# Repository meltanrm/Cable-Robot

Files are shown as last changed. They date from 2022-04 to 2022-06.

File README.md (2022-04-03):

# Cable-Robot

In this repo, you will find:
- Stl files of 3D printed parts that will enable you to make your cable robot (under Stl_files: Camera_mount, Prototype and Final_frame designs).
- Code to test the electronic setup for your cable robot (in the Electronics_testing_code folder), which you are recommended to go through in the following order:
  1. Test_motors
  2. Test_encoder
  3. Test_encoder_tracking_motor
  4. Joystick_graphs
  5. Test_joystick
- Code to run your cable robot, moving it to desired positions (Prototype_cable_robot_code).

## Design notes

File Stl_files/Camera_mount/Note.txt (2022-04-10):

All camera mount stl files, except "Raspi Backboard attached to rail slider Final v1.stl", were designed by fl0r1s. They were uploaded on Thingiverse on 21st January 2021 at this link: https://www.thingiverse.com/thing:4731754 (Accessed 2nd April 2022)

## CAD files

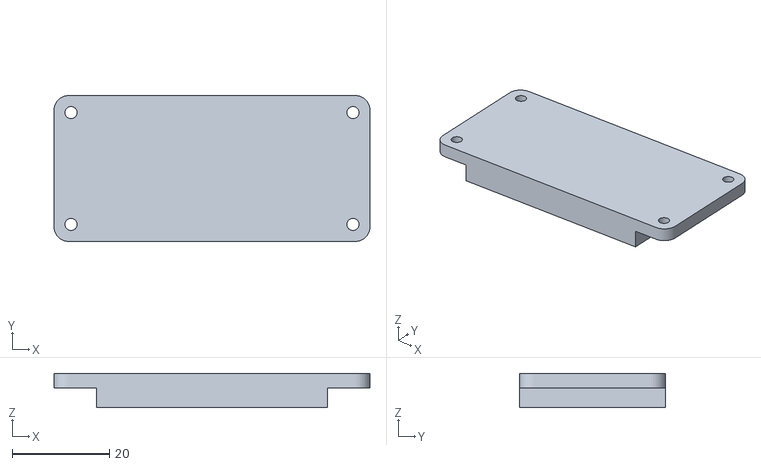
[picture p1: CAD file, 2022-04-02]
Stl_files/Camera_mount/interface.stl
65.0 x 30.0 x 7.00

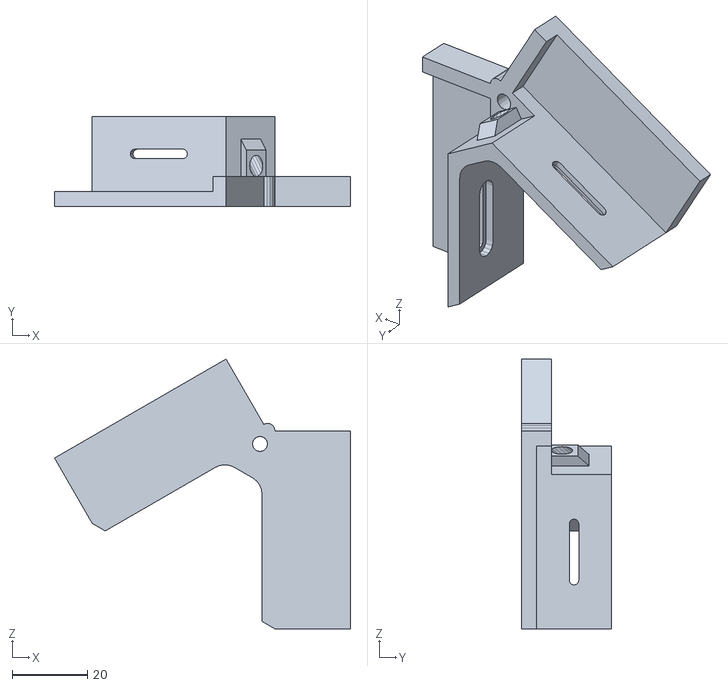
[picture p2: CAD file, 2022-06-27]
Stl_files/Final_frame/PlatformCorner.stl
78.5 x 24.0 x 71.6

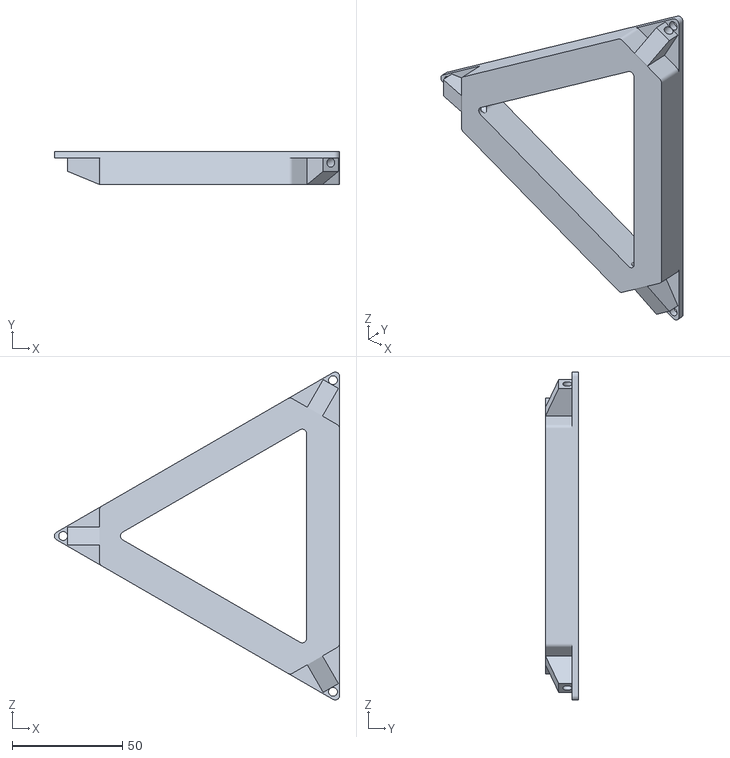
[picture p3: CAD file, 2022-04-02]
Stl_files/Prototype/Platform.stl
129.6 x 15.0 x 149.0

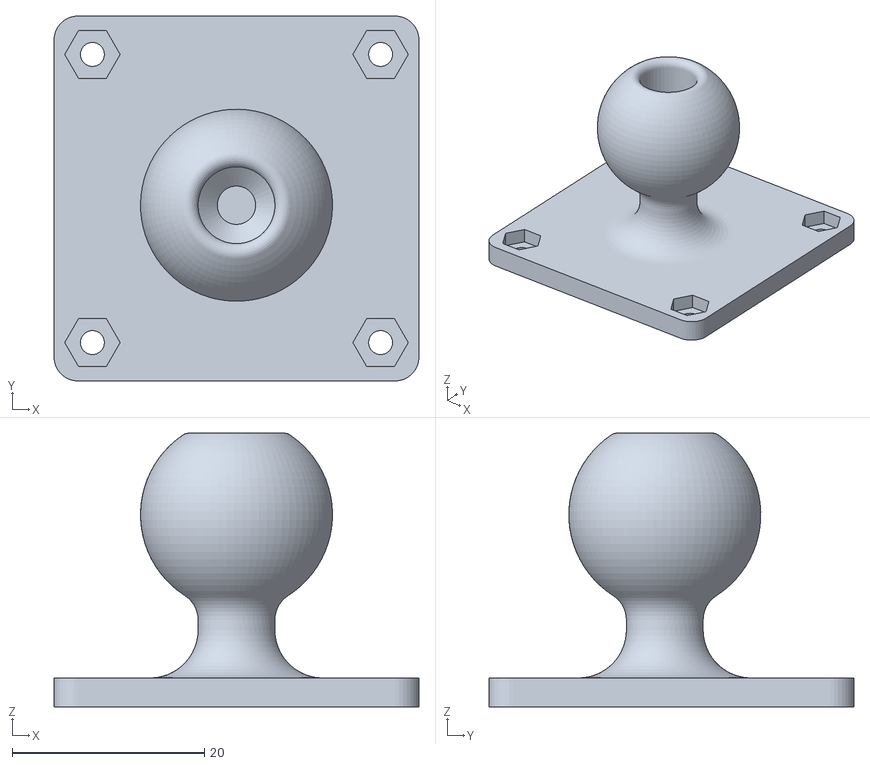
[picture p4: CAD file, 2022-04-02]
Stl_files/Camera_mount/ball.stl
38.0 x 38.0 x 28.5

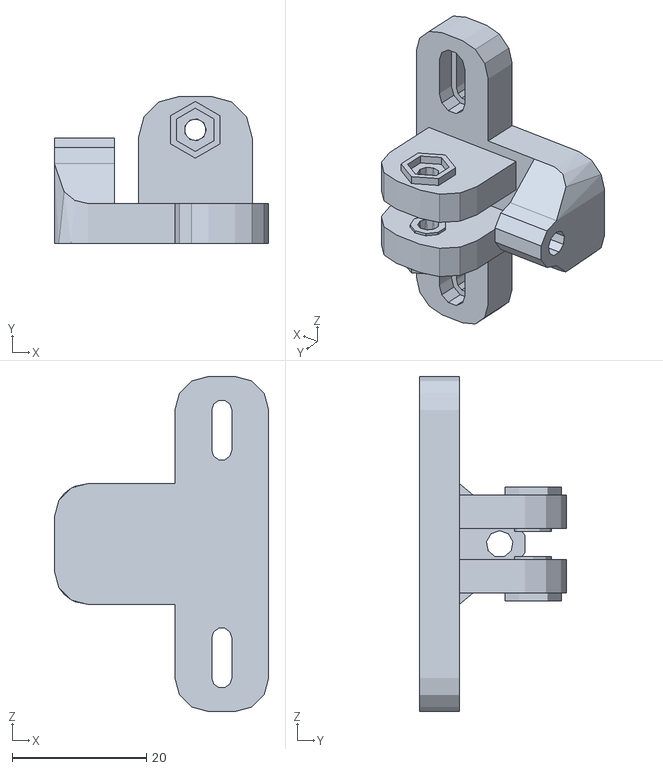
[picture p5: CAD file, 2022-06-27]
Stl_files/Final_frame/LineAnchors.stl
32.0 x 22.0 x 50.0

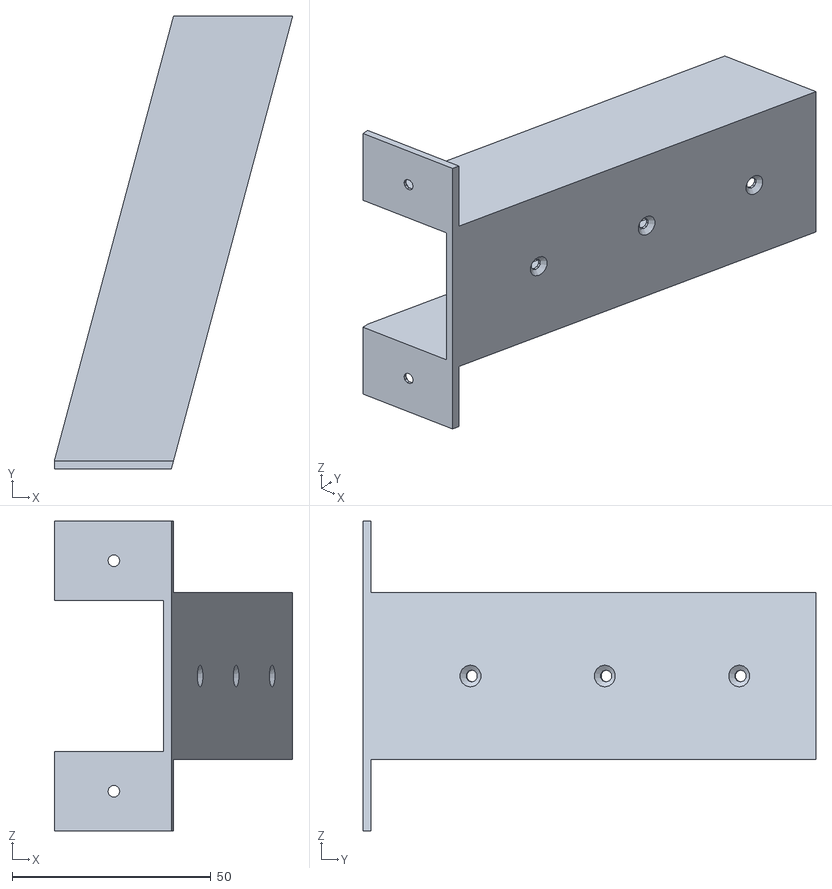
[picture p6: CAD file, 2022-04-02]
Stl_files/Prototype/OuterLeaningCase.stl
60.0 x 114.0 x 78.0

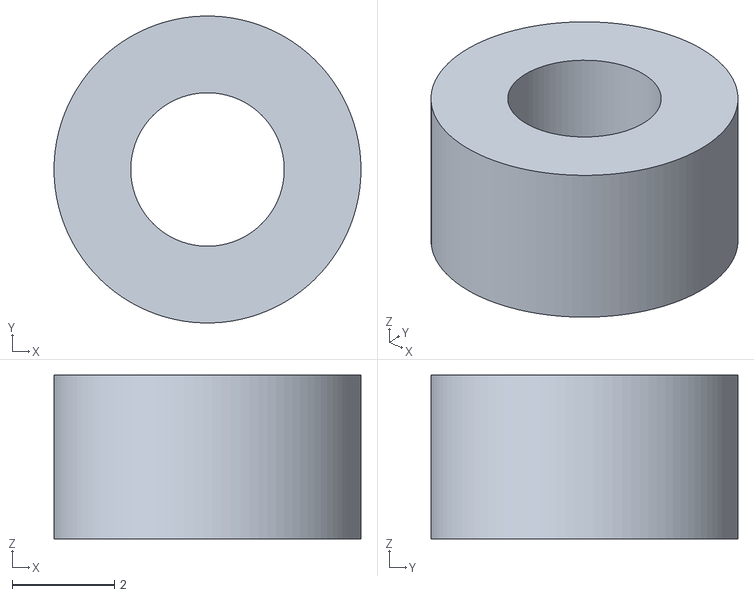
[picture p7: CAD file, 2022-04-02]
Stl_files/Camera_mount/spacer.stl
6.00 x 6.00 x 3.20

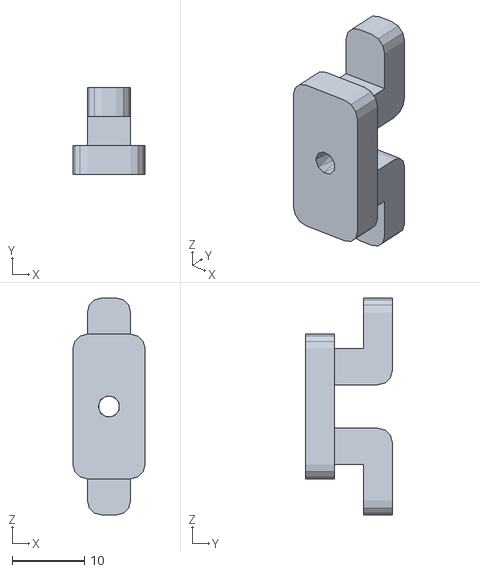
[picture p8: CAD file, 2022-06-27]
Stl_files/Final_frame/PlatformSlider.stl
10.0 x 12.0 x 30.0

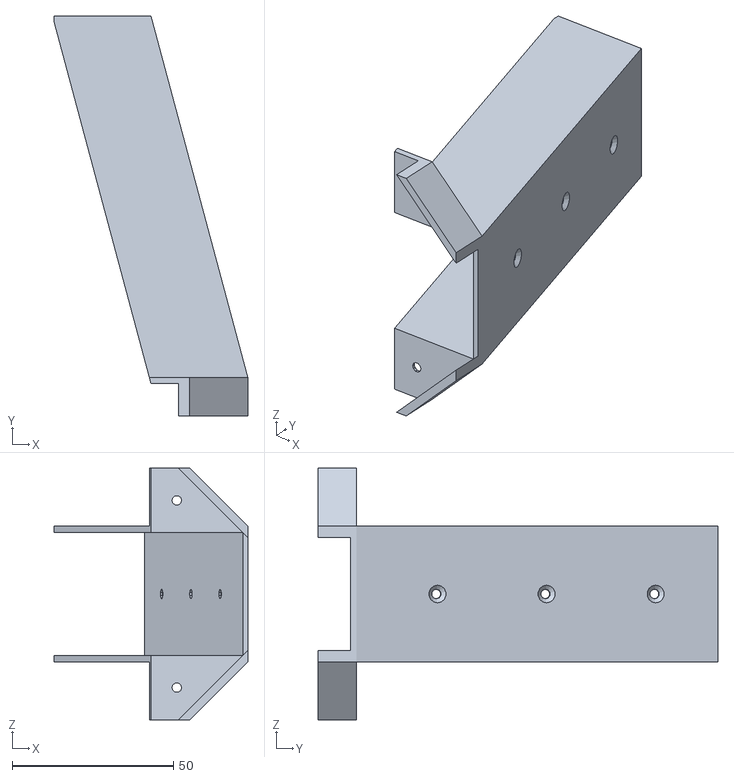
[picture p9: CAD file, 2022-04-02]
Stl_files/Prototype/Leaning beam case v2.stl
60.0 x 124.0 x 78.0

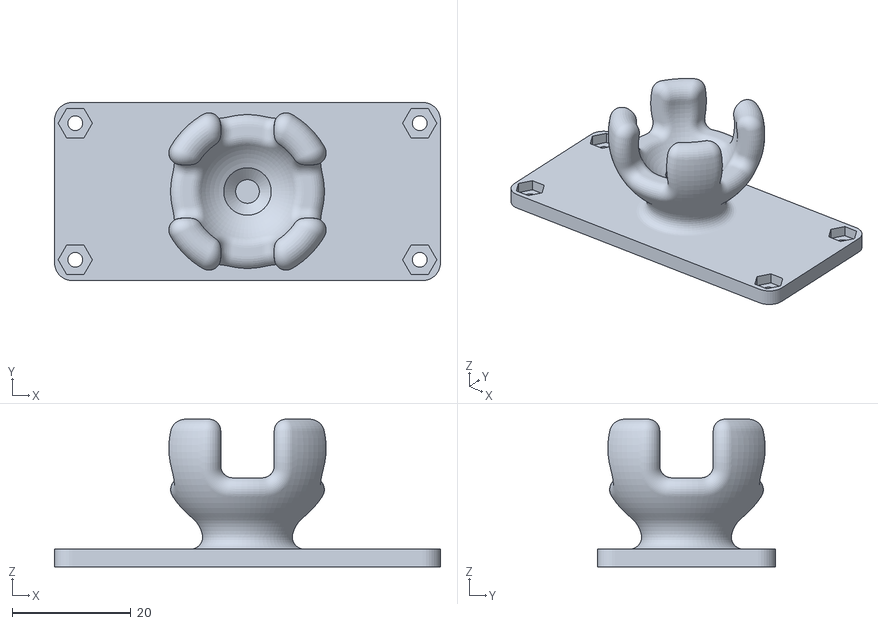
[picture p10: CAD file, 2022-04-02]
Stl_files/Camera_mount/socket.stl
65.0 x 30.0 x 24.9

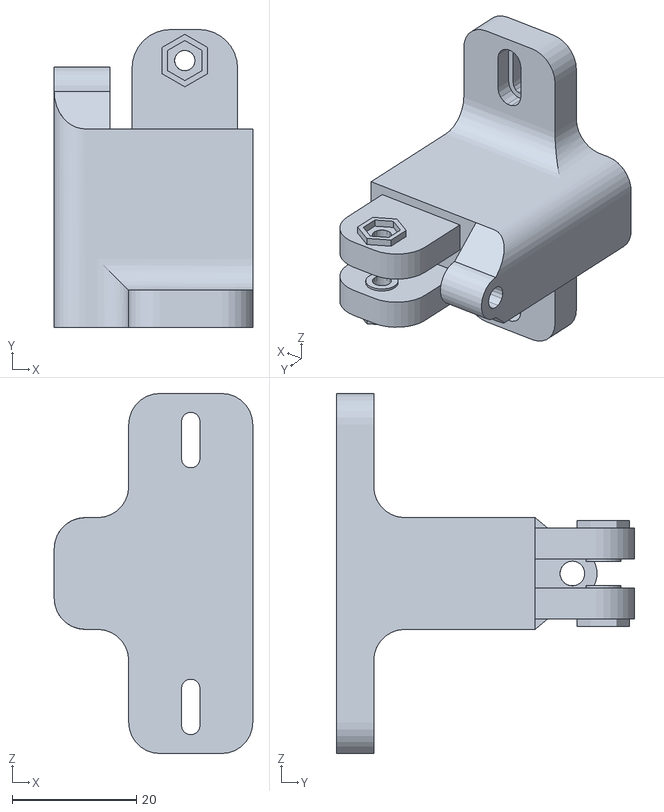
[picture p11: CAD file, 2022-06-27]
Stl_files/Final_frame/LineAnchors_C.stl
32.0 x 48.0 x 58.0

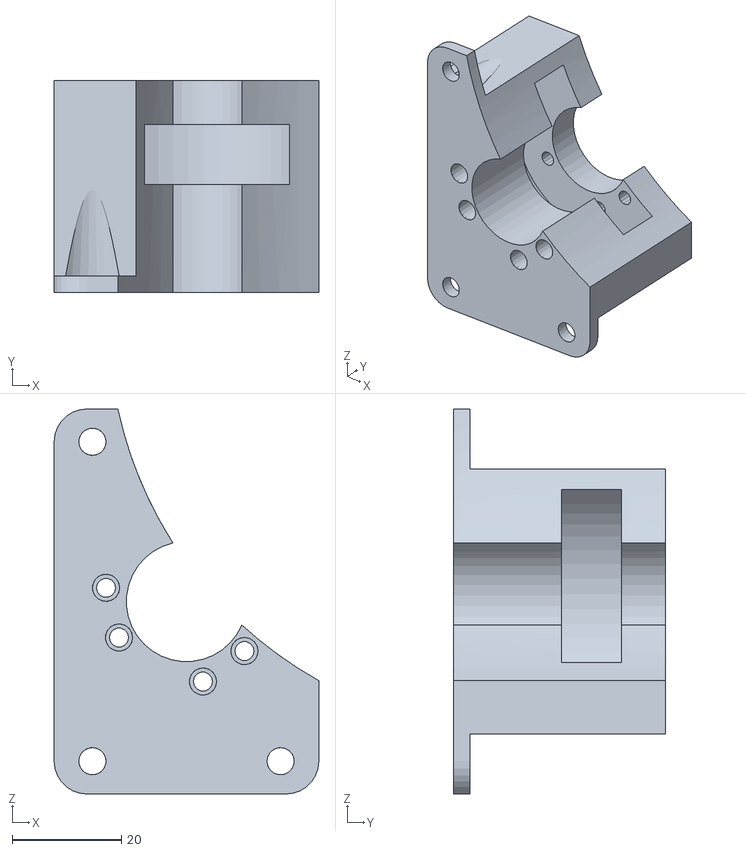
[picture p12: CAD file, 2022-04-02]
Stl_files/Prototype/Encoder_bracket.stl
48.4 x 38.7 x 70.4

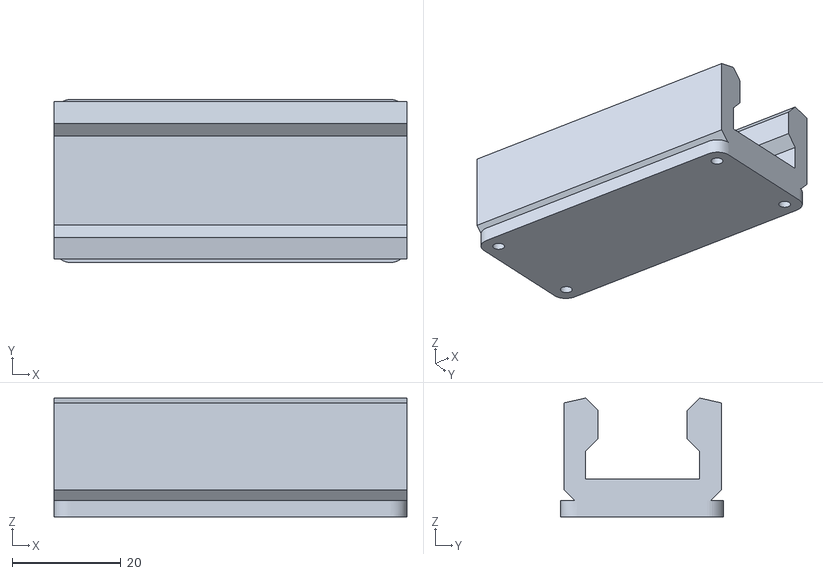
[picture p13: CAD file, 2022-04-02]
Stl_files/Camera_mount/Raspi Backboard attached to rail slider Final v1.stl
65.0 x 30.0 x 21.9

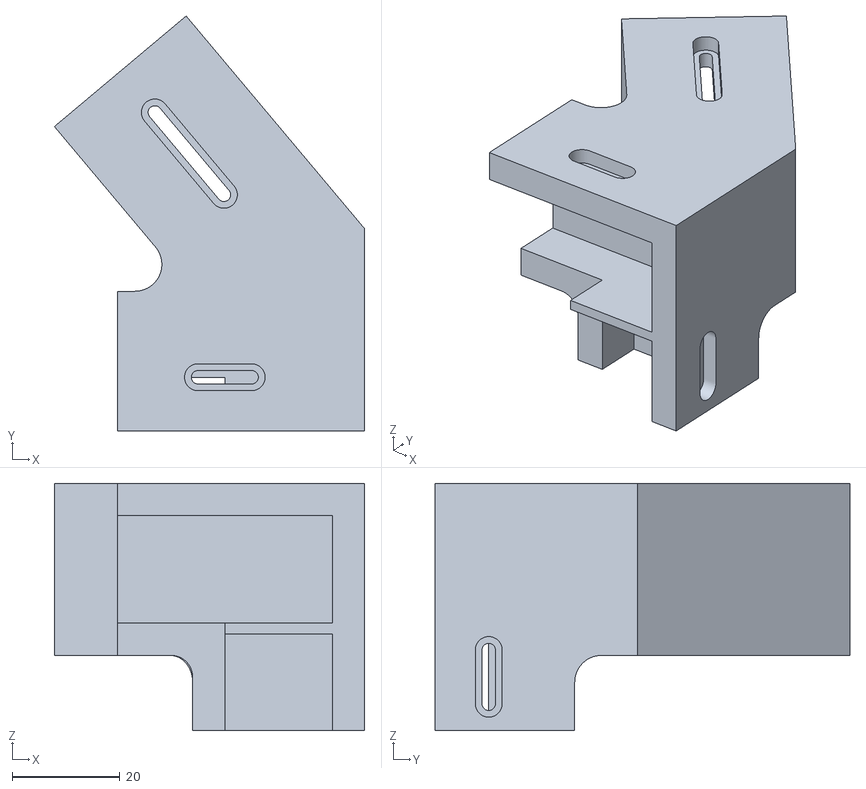
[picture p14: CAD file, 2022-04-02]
Stl_files/Final_frame/LowerConnect_finalShortBeam.stl
57.7 x 77.2 x 46.0

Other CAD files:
Stl_files/Final_frame/LowerConnect_finalMirror.stl
Stl_files/Final_frame/UpperConnect_finalShortBeam.stl
Stl_files/Final_frame/DiagonalBeamBracket_2.stl
Stl_files/Final_frame/DiagonalBeamBracket_2_Mirror.stl
Inventor_Files/CalibrationRig_ver2.ipt
Inventor_Files/PlatformSlider.ipt
Stl_files/Final_frame/DiagonalBeamBracket.stl
Stl_files/Final_frame/DiagonalBeamBracket_Mirror.stl
Stl_files/Final_frame/LowerConnect_final.stl
Stl_files/Final_frame/UpperConnect_final.stl

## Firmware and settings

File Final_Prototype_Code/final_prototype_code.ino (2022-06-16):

// Code to move final design of cable robot - 16 June 2022

// NOTES:
// Set the serial monitor from newline --> no line ending
// All input coordinates are in cm
// All coordinates, cable lengths and spool dimensions are in cm

// Pins and motors set-up: direction and steps
  const int dirPinA = 10; // motor A
  const int stepPinA = 11;
  const int dirPinB = 6; // motor B
  const int stepPinB = 7;
  const int dirPinC = 12; // motor C
  const int stepPinC = 13;
  const int dirPinD = 8; // motor D spool
  const int stepPinD = 9;

// Initialising coordinates of platform
float P[3] = {0, 0, 0};

void setup() {
  Serial.begin(9600);

  // Declaring pins as outputs
    pinMode(stepPinA, OUTPUT);
    pinMode(dirPinA, OUTPUT);
    pinMode(stepPinB, OUTPUT);
    pinMode(dirPinB, OUTPUT);
    pinMode(stepPinC, OUTPUT);
    pinMode(dirPinC, OUTPUT);
    pinMode(stepPinD, OUTPUT);
    pinMode(dirPinD, OUTPUT);
}

// Function to receive input coordinates:

void recvInputCoord() {

  float bounds_x[] = {-33.5,28.0};
  float bounds_y[] = {-50.5,50.5};
  float bounds_z[] = {0,30};
  
  bool dum = true;

  while(dum){
    int counter = 0;
    Serial.println("Please input X coordinate: "); //Prompt User for Input
    while (Serial.available() == 0) {
    }
    P[0] = Serial.parseInt();
  
    Serial.println("Please input Y coordinate: "); //Prompt User for Input
    while (Serial.available() == 0) {
    }
    P[1] = Serial.parseInt();
  
    Serial.println("Please input Z coordinate: "); //Prompt User for Input
    while (Serial.available() == 0) {
    }
    P[2] = Serial.parseInt();

    if ((P[0] < bounds_x[0]) || (P[0] > bounds_x[1])) {
      counter++;
    }
    if ((P[1] < bounds_y[0]) || (P[1] > bounds_y[1])) {
      counter++;
    }
    if ((P[2] < bounds_z[0]) || (P[2] > bounds_z[1])) {
      counter++;
    }
    if (counter == 0) {
      dum = false;
      break;
    }

    Serial.println("Sorry, you input was out of bounds.");
    Serial.println("Please input coordinates within the boundaries.");
    Serial.println("X bounds: -33.5 to 28.0 cm");
    Serial.println("Y bounds: -50.5 to 50.5 cm");
    Serial.println("Z bounds: 0 to 30 cm"); 
  }
  
  Serial.println("Your input coordinates are: ");
  Serial.println(P[0]);
  Serial.println(P[1]);
  Serial.println(P[2]);
}

// Function to calculate cable lengths:

float cableLength(float coord1[3], float coord2[3]) {
     float diff[3];
     float modResult;
     for (int i = 0; i < 3; i++) {
        diff[i] = (coord2[i] - coord1[i]); 
     }
     modResult = (sqrt(sq(diff[0]) + sq(diff[1]) + sq(diff[2])));  
     
     return modResult;
}

void loop() {

  // Initialise cableLength function
     float cableLength(float coord1[], float coord2[]);

  // Height of prototype
    float height_upper = 56.4196 - 26.6; // relative to height of line anchors
    float height_lower = 0; // height of line anchors set as zero

  // Coordinates of line rollers for D spool (used below)
    float D1[] = {4.8948, 0, height_upper};
    float D2[] = {-12.5185, -10.0536, height_upper};
    float D3[] = {-12.5185, 10.0536, height_upper};

  // Coordinates of platform vertices at starting position
    float P1_0[]= {D1[0], D1[1], height_lower};
    float P2_0[]= {D2[0], D2[1], height_lower};
    float P3_0[]= {D3[0], D3[1], height_lower};

  // Coordinates of line anchors
    float a1[] = {28.6891, -41.2129, height_lower};
    float a2[] = {11.2757, -51.2665, height_lower};
    float b1[] = {28.6891, 41.2129, height_lower};
    float b2[] = {11.2757, 51.2665, height_lower};
    float c1[] = {-34.0, -10.0536, height_lower};
    float c2[] = {-34.0, 10.0536, height_lower};

  // Cable lengths at starting point
    // Two cables (1 and 2) come from each of the spools (A to C)
    // Three cables come from spool D
    // Distance calculated: line anchors to platform vertices
      float l_a1_0 = 47.5885;
      float l_a2_0 = 47.5885;
      float l_b1_0 = 47.5885;
      float l_b2_0 = 47.5885;
      float l_c1_0 = 21.4815;
      float l_c2_0 = 21.4815;
      float l_d1_0 = height_upper; // Applies only at start when cables are vertical
      float l_d2_0 = height_upper; 
      float l_d3_0 = height_upper;
  
  // Receives input coordinates
    recvInputCoord();

  // Coordinates of 3 platform vertices at new position
    float v1[] = {D1[0] + P[0], D1[1] + P[1], D1[2] + P[2]};
    float v2[] = {D2[0] + P[0], D2[1] + P[1], D2[2] + P[2]}; 
    float v3[] = {D3[0] + P[0], D3[1] + P[1], D3[2] + P[2]};

 // Cable lengths at new position
    // Distance calculated: line anchors to platform vertices
    float l_a1 = cableLength(a1, v1);
    float l_a2 = cableLength(a2, v2);
    float l_b1 = cableLength(b1, v1);
    float l_b2 = cableLength(b2, v3);
    float l_c1 = cableLength(c1, v2);
    float l_c2 = cableLength(c2, v3);
    float l_d1 = cableLength(v1, D1);
    float l_d2 = cableLength(v2, D2);
    float l_d3 = cableLength(v3, D3);
      

 // Calculate cable length difference: desired length - current length
    // Only required to be calculated for one cable per spool - works geometrically 
    float lineDiffa1 = l_a1 - l_a1_0; 
    float lineDiffb1 = l_b1 - l_b1_0;
    float lineDiffc1 = l_c1 - l_c1_0;
    float lineDiffd1 = l_d1 - l_d1_0; 

 // Moving the motors by desired amount
    // Finding the corresponding rotations required
    float spoolDiameter = 11;
    float spoolCirc = PI * spoolDiameter;
    
    // 200 motor steps per motor turn --> 10 motor turns = 1 spool turn
    int motorSteps_a1 = ((lineDiffa1) / (spoolCirc)) * 10 * 200; 
    int motorSteps_b1 = ((lineDiffb1) / (spoolCirc)) * 10 * 200;
    int motorSteps_c1 = ((lineDiffc1) / (spoolCirc)) * 10 * 200;
    int motorSteps_d1 = ((lineDiffd1) / (spoolCirc)) * 10 * 200;

    // Absolute values of motor steps
    int abs_a = abs(motorSteps_a1);
    int abs_b = abs(motorSteps_b1);
    int abs_c = abs(motorSteps_c1);
    int abs_d = abs(motorSteps_d1);
  
    int stepsArray[] = {abs_a,abs_b,abs_c,abs_d};
    
        // for checking the number of motor steps per spool:
         /* Serial.println("These are the motor steps:");
            Serial.println(abs_a);
            Serial.println(abs_b);
            Serial.println(abs_c);
            Serial.println(abs_d); */

    // Large 'for' loop to set motors to move at the same time
      // Loop continues until value of counter reaches value of motor steps
      // For all 4 spools: set direction of turns, comparison of counter vs. motorsteps, 
      // set pin HIGH, delay, set pin LOW.
    
      // Compare all 4 values to find highest
      int highVal = stepsArray[0];
      for (int n = 1; n < 4; n++) {
         if (stepsArray[n] > highVal) {
              highVal = stepsArray[n];
         }
      }
  
      // Counters
      int count_a = 0;
      int count_b = 0;
      int count_c = 0;
      int count_d = 0;

      for(int x = 0; x < highVal; x++){
        // Set direction of pins
          if (lineDiffa1 > 0){
            digitalWrite(dirPinA, LOW);
          }
          else {
            digitalWrite(dirPinA, HIGH);
          }
          
          if (lineDiffb1 > 0){
            digitalWrite(dirPinB, HIGH);
          }
          else {
            digitalWrite(dirPinB, LOW);
          }
          
          if (lineDiffc1 > 0){
            digitalWrite(dirPinC, LOW);
          }
          else {
            digitalWrite(dirPinC, HIGH);
          }
          
          if (lineDiffd1 > 0){
            digitalWrite(dirPinD, HIGH);
          }
          else {
            digitalWrite(dirPinD, LOW);
          }

        // Set pins HIGH
          if (count_a < abs_a) {
            digitalWrite(stepPinA, HIGH);
          }
          if (count_b < abs_b) {
            digitalWrite(stepPinB, HIGH);
          }
          if (count_c < abs_c) {
            digitalWrite(stepPinC, HIGH);
          }
          if (count_d < abs_d) {
            digitalWrite(stepPinD, HIGH);
          }


        // Delay 
          if (count_a < abs_a||count_b < abs_b||count_c < abs_c||count_d < abs_d) {
            delayMicroseconds(1000);
          }

        // Set pins LOW
          if (count_a < abs_a) {
            digitalWrite(stepPinA, LOW);
          }
          if (count_b < abs_b) {
            digitalWrite(stepPinB, LOW);
          }
          if (count_c < abs_c) {
            digitalWrite(stepPinC, LOW);
          }
          if (count_d < abs_d) {
            digitalWrite(stepPinD, LOW);
          }
          
        // Delay 
          if (count_a < abs_a||count_b < abs_b||count_c < abs_c||count_d < abs_d) {
            delayMicroseconds(1000);
          }
          
       // Update counters
        count_a = count_a + 1;
        count_b = count_b + 1;
        count_c = count_c + 1;
        count_d = count_d + 1;
      
      }
  
  // reassign values of lengths
      l_a1_0 = l_a1;
      l_a2_0 = l_a2;
      l_b1_0 = l_b1;
      l_b2_0 = l_b2;
      l_c1_0 = l_c1;
      l_c2_0 = l_c2;
      l_d1_0 = l_d1;
      l_d2_0 = l_d2;
      l_d3_0 = l_d3;

}

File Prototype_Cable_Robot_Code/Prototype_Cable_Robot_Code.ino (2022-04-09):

// set serial monitor settings (newline --> no line ending)

const int dirPinB = 6; // motor B
const int stepPinB = 7;
const int dirPinD = 8; // motor D spool
const int stepPinD = 9;
const int dirPinA = 10; // motor A
const int stepPinA = 11;
const int dirPinC = 12; // motor C
const int stepPinC = 13;
const int stepsPerRevolution = 200;
float Cp[3] = {0, 0, 0};

void setup() {
  Serial.begin(9600);

  // Declare motor control pins as Outputs
  pinMode(stepPinB, OUTPUT);
  pinMode(dirPinB, OUTPUT);
  pinMode(stepPinD, OUTPUT);
  pinMode(dirPinD, OUTPUT);
  pinMode(stepPinA, OUTPUT);
  pinMode(dirPinA, OUTPUT);
  pinMode(stepPinC, OUTPUT);
  pinMode(dirPinC, OUTPUT);

}


void recvInputCoord() {
  float x_coord;
  float y_coord;
  float z_coord;
 
  Serial.begin(9600);

  Serial.println("Please input X coordinate: ");
  while (Serial.available() == 0) {
  }
  x_coord = Serial.parseInt();
  Serial.println(x_coord);

  Serial.println("Please input Y coordinate: "); // Prompt User for Input
  while (Serial.available() == 0) {
  }
  y_coord = Serial.parseInt();
  Serial.println(y_coord);

  Serial.println("Please input Z coordinate: "); // Prompt User for Input
  while (Serial.available() == 0) {
  }
  z_coord = Serial.parseInt();
  //Serial.println(z_coord);

// all input coordinates in cm 
  Cp[0] = x_coord;
  Cp[1] = y_coord;
  Cp[2] = z_coord;

  Serial.println("Your input coordinates are: ");
  Serial.println(x_coord);
  Serial.println(y_coord);
  Serial.println(z_coord);
}

    // Function calculates line length
    float lineLength(float coord1[3], float coord2[3]) {
      float diff[3];
      float modResult;
      for (int i = 0; i < 3; i++) {
        diff[i] = (coord2[i] - coord1[i]);  // coordinates in cm
      }
      modResult = (sqrt(sq(diff[0]) + sq(diff[1]) + sq(diff[2]))); // modResut in cm
      return modResult;
    }

void loop() {
  float lineLength(float coord1[], float coord2[]);

  float height_upper = 1.397*100; // height (in cm) from top board to level with frame (0.038m above the ground)
  float height_lower = 0; 

  // coord of line rollers and vertices(for D), all outputs in cm
  float D_1[] = { -70.785 / 10, -40.865 / 10, height_upper};
  float D_1atplat[] = { -70.785 / 10, -40.865 / 10, height_lower};
  float D_2[] = {0, 80.736 / 100, height_upper};
  float D_2atplat[] = {0, 80.736 / 10, height_lower};
  float D_3[] = {70.785 / 10, 40.865 / 10, height_upper};
  float D_3atplat[] = {70.785 / 10, 40.865 / 10, height_lower};
  
  // coord of line anchors
  float a1_1[] = { -70.785 / 10, -530 / 10, height_lower};
  float a1_2[] = {70.785 / 10, -530 / 10, height_lower};
  float a2_1[] = { -530 / 10, 224.26 / 10, height_lower};
  float a2_2[] = { -530 / 10, 387.731 / 10, height_lower};
  float a3_1[] = {530 / 10, 387.731 / 10, height_lower};
  float a3_2[] = {530 / 10, 224.26 / 10, height_lower};

  // line lengths at origin
  // only distance that is necessry is the line anchor to the platform vertex (we only care about changes in lengths)
  float l_a1_0 = lineLength(a2_1, D_1atplat);
  float l_a2_0 = lineLength(a2_2, D_2atplat);
  float l_b1_0 = lineLength(a1_1, D_3atplat);
  float l_b2_0 = lineLength(a1_2, D_1atplat);
  float l_c1_0 = lineLength(a3_1, D_2atplat);
  float l_c2_0 = lineLength(a3_2, D_3atplat);

  float l_d1_0 = lineLength(D_1atplat, D_1); // from line D rollers to platform vertices
  float l_d2_0 = lineLength(D_2atplat, D_2);
  float l_d3_0 = lineLength(D_3atplat, D_3);


  recvInputCoord(); // receives input coordinates in cm, converted to metres in function

  // coordinates of triangle platform vertices with respect to the center of platform, Cp
  float V_1[] = {D_1[0] + Cp[0], D_1[1] + Cp[1], 0 + Cp[2]}; // lined up with D_1
  float V_2[] = {D_2[0] + Cp[0], D_2[1] + Cp[1], 0 + Cp[2]}; // lined up with D_2
  float V_3[] = {D_3[0] + Cp[0], D_3[1] + Cp[1], 0 + Cp[2]}; // lined up with D_3

  // calculation of cable lengths
  // total change in lengths from one point to another = (spool to roller) + (roller to anchor) + (anchor to platform vertex)
  float l_a1 = lineLength(a2_1, V_1);
  float l_a2 = lineLength(a2_2, V_2);
  float l_b1 = lineLength(a1_1, V_3);
  float l_b2 = lineLength(a1_2, V_1);
  float l_c1 = lineLength(a3_1, V_2);
  float l_c2 = lineLength(a3_2, V_3);

  float l_d1 = lineLength(V_1, D_1); 
  float l_d2 = lineLength(V_2, D_2);
  float l_d3 = lineLength(V_3, D_3);

  // calculate difference between desired lengths and current lengths
  float lineDiffa1 = l_a1 - l_a1_0; // repeated for all other lines
  float lineDiffa2 = l_a2 - l_a2_0;
  float lineDiffb1 = l_b1 - l_b1_0;
  float lineDiffb2 = l_b2 - l_b2_0;
  float lineDiffc1 = l_c1 - l_c1_0;
  float lineDiffc2 = l_c2 - l_c2_0;
  float lineDiffd1 = l_d1 - l_d1_0; // lineDiff for D
  float lineDiffd2 = l_d2 - l_d2_0;
  float lineDiffd3 = l_d3 - l_d3_0;

  // find the corresponding rotations required
  float spoolDiameter = 11; // in cm
  float spoolCirc = PI * spoolDiameter;

  // for each of the below, a1 and a2 should be equal, same for b1 and b2, and c1 and c2
  // 10 turns of motor is one turn of spool; motor has 200 steps per turn 
  int motorSteps_a1 = ((lineDiffa1) / (spoolCirc)) * 10 * 200; 
  int motorSteps_b1 = ((lineDiffb1) / (spoolCirc)) * 10 * 200;
  int motorSteps_c1 = ((lineDiffc1) / (spoolCirc)) * 10 * 200;
  int motorSteps_d1 = ((lineDiffd1) / (spoolCirc)) * 10 * 200;
  
  int abs_a = abs(motorSteps_a1);
  int abs_b = abs(motorSteps_b1);
  int abs_c = abs(motorSteps_c1);
  int abs_d = abs(motorSteps_d1);
  
  int stepsArray[] = {abs_a,abs_b,abs_c,abs_d};

  // for checking the number of motor steps per spool:
   /* Serial.println("These are the motor steps:");
      Serial.println(abs_a);
      Serial.println(abs_b);
      Serial.println(abs_c);
      Serial.println(abs_d); */

// Compare all 4 values to find highest
  int highVal = stepsArray[0];
  for (int n = 1; n < 4; n++) {
   if (stepsArray[n] > highVal) {
        highVal = stepsArray[n];
   }
  }
  
//  COUNTERS
  int count_a = 0;
  int count_b = 0;
  int count_c = 0;
  int count_d = 0;
  
  for(int x = 0; x < highVal; x++){
//  set clockwise or anticlockwise
    if (lineDiffa1 > 0){
      digitalWrite(dirPinA, LOW);
    }
    else {
      digitalWrite(dirPinA, HIGH);
    }
    
    if (lineDiffb1 > 0){
      digitalWrite(dirPinB, HIGH);
    }
    else {
      digitalWrite(dirPinB, LOW);
    }
    
    if (lineDiffc1 > 0){
      digitalWrite(dirPinC, HIGH);
    }
    else {
      digitalWrite(dirPinC, LOW);
    }
    
    if (lineDiffd1 > 0){
      digitalWrite(dirPinD, HIGH);
    }
    else {
      digitalWrite(dirPinD, LOW);
    }
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

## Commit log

2022-01-27 Create encoder_to_motor.ino
    initial code: one encoder to one motor
2022-01-27 Create encoder_testing.ino
    tests encoder with serial monitor
2022-01-27 Uploading all our Arduino code
    And created a folder for each code file, otherwise they won't open
    [Joystick_graphs.ino, Move_motors.ino]
2022-01-28 Final encoder/motor/driver code
2022-02-03 added code that tests motor moving encoder
2022-02-04 Create fullcode_v2.ino
    has keypad + revised motor code
2022-02-04 renaming motors to match with calculations
2022-02-07 Create fullcode_v3.ino
    problems: line 52 (curly bracket?), what are sizes of coord2[] and coord1[]? (also, not really sure what coord1 and coord2 are), line 280 (some problem with sq/sqrt function)
2022-03-08 Create fullcode_v6.ino
    New version with motors moving simultaneously
2022-04-01 Update Encoder_to_motor.ino
    Formatted brackets
2022-04-02 Rename cableRobot copy.ino to fullcode_versions/cableRobot copy.ino
2022-04-02 Create Camera Mount CAD
2022-04-02 Regrouped stl files on a folder
    [DiagonalBeamBracket.stl, DiagonalBeamBracket_2.stl, DiagonalBeamBracket_2_Mirror.stl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]
2022-04-03 Rename fullcode_versions/cableRobot.ino to version history/cableRobot.ino
2022-04-03 Rename version history/cableRobot.ino to final version history/cableRobot.ino
2022-04-03 Rename fullcode_versions/cableRobot copy.ino to final version history/cableRobot copy.ino
2022-04-03 New folder for camera mount stl files
    [Raspi Backboard attached to rail slider Final v1.stl, ball.stl, interface.stl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]
2022-04-09 Fixed typos in comments
    [Prototype_Cable_Robot_Code.ino]
2022-04-10 added reference note on where stl files are from
2022-05-05 Code structure
    Code structure for the final prototype - coordinates, pins and dimensions still need to be added.
2022-05-28 First review update
    - pins added
    - coordinates changed from cm to mm
    - cable lengths changed for C spool
    - anchor coordinates added
    - use of cable length function
    - ALL HEIGHTS CALCULATED WRT HEIGHT OF LINE ANCHORS
2022-05-29 Update final_prototype_code.ino
    fixed error message for bounds function
    [final_prototype_code.ino]
2022-06-15 Update final_prototype_code.ino
    Switched directions of motor C
